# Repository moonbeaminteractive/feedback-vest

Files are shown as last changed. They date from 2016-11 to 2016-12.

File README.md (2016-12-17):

# feedback-vest
vest with haptic and visual feedback

## Circuit Diagram - main board
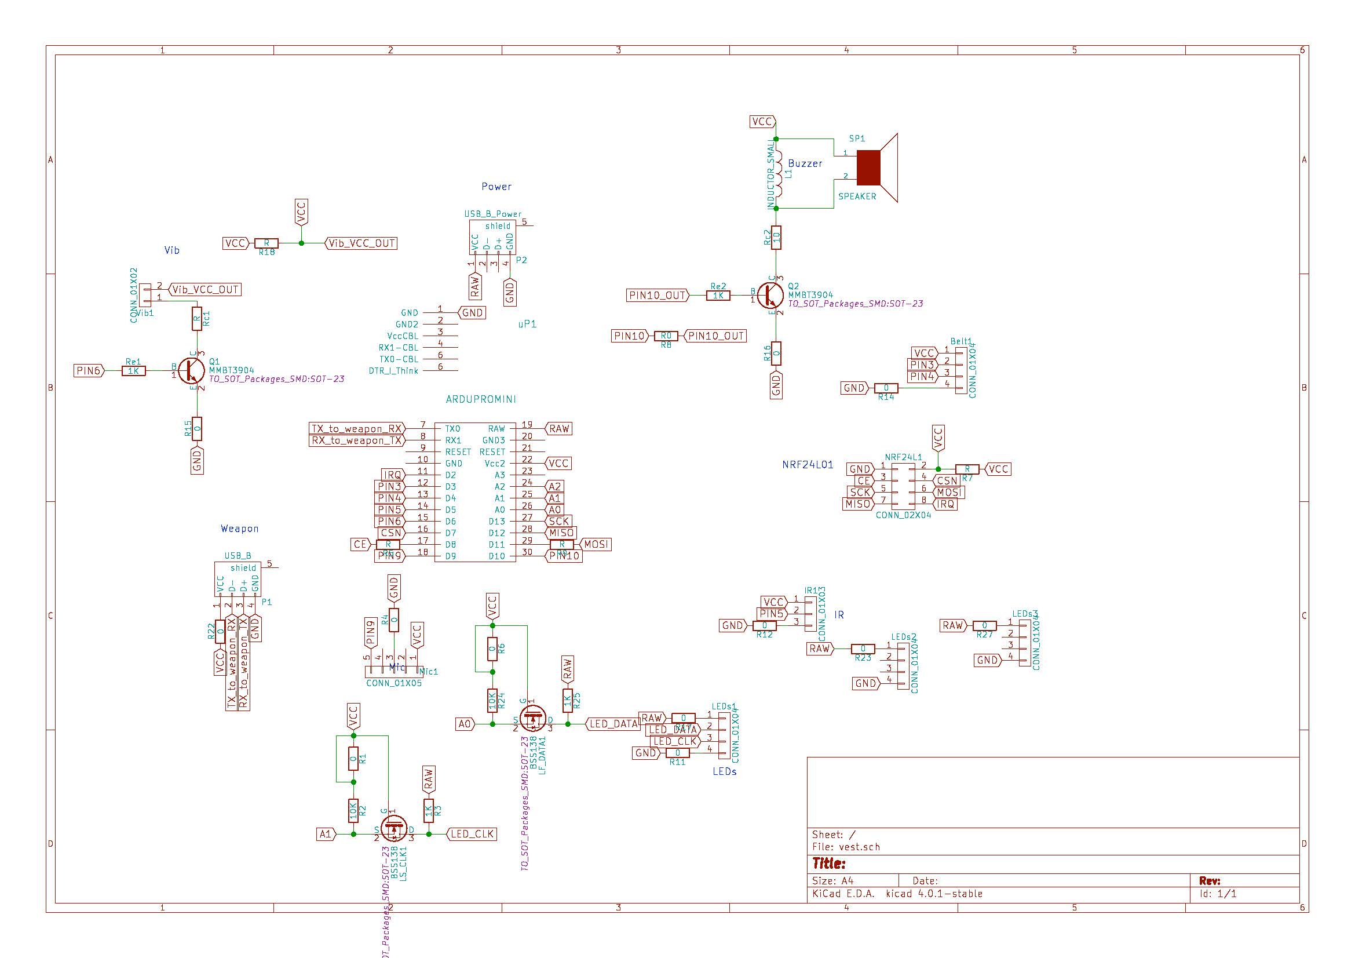
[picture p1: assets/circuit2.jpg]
alt circuit


## PCB - main board
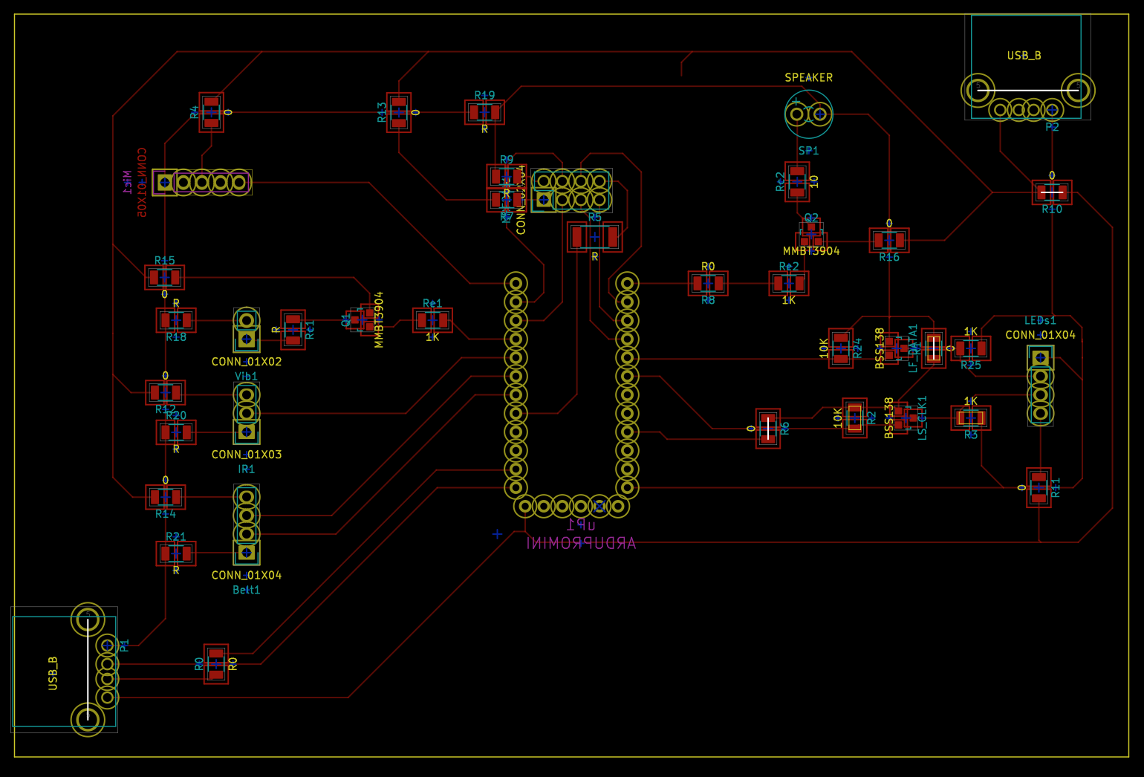
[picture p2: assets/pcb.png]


## Circuit Diagram - led Ring
alt circuit
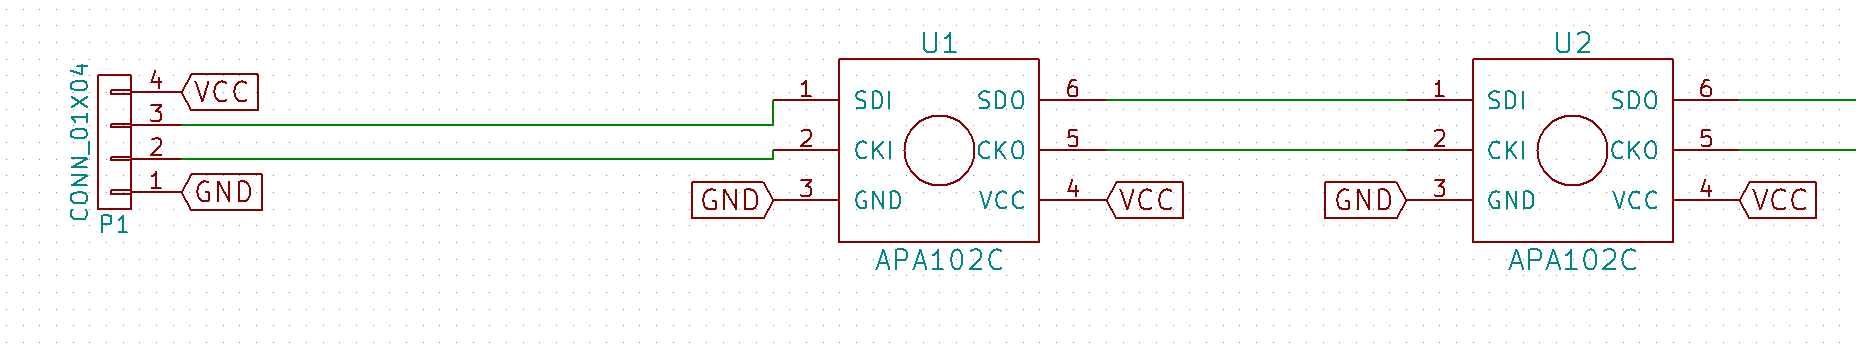
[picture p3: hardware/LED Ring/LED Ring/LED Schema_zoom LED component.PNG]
alt circuit_led component


## Circuit Diagram - led ring PCB
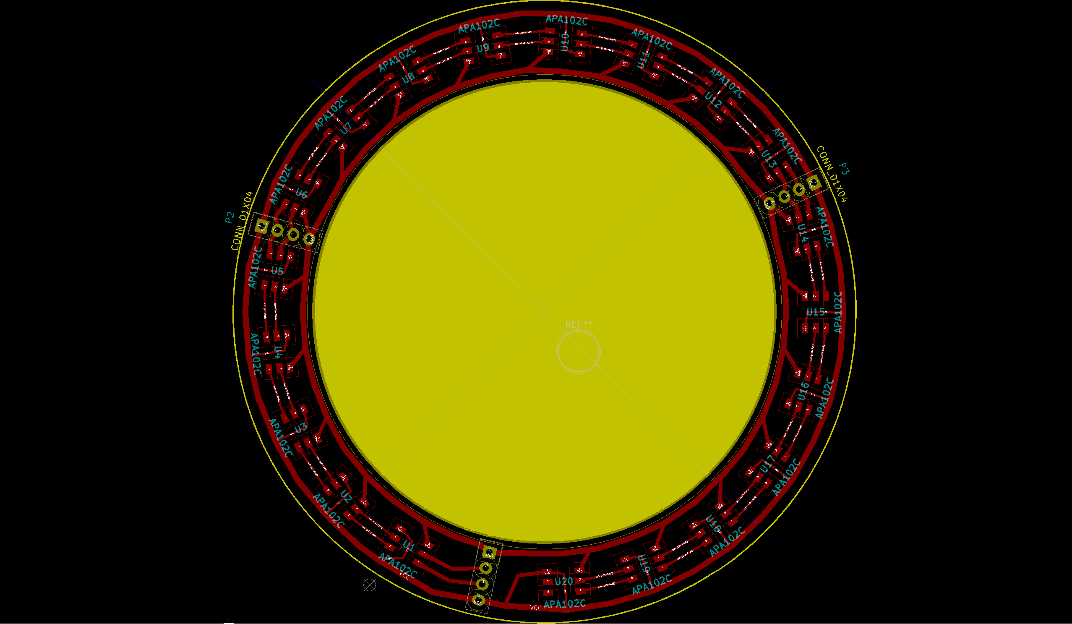
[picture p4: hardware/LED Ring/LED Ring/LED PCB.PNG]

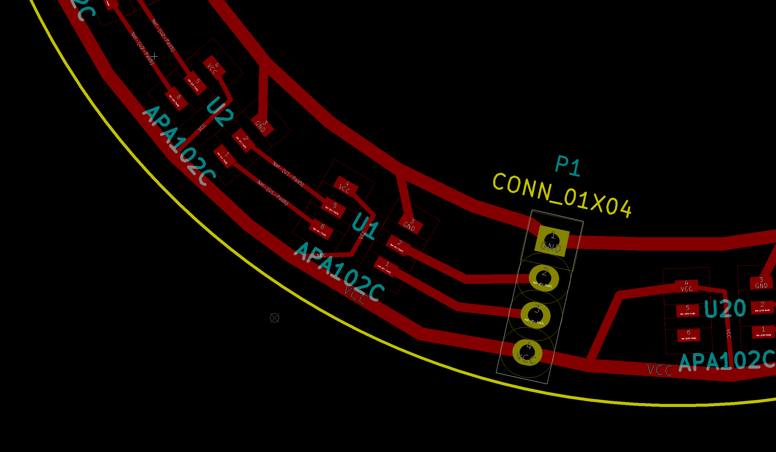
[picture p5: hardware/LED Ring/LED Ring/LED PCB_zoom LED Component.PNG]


## circuit diagram and PCB - IR sensors
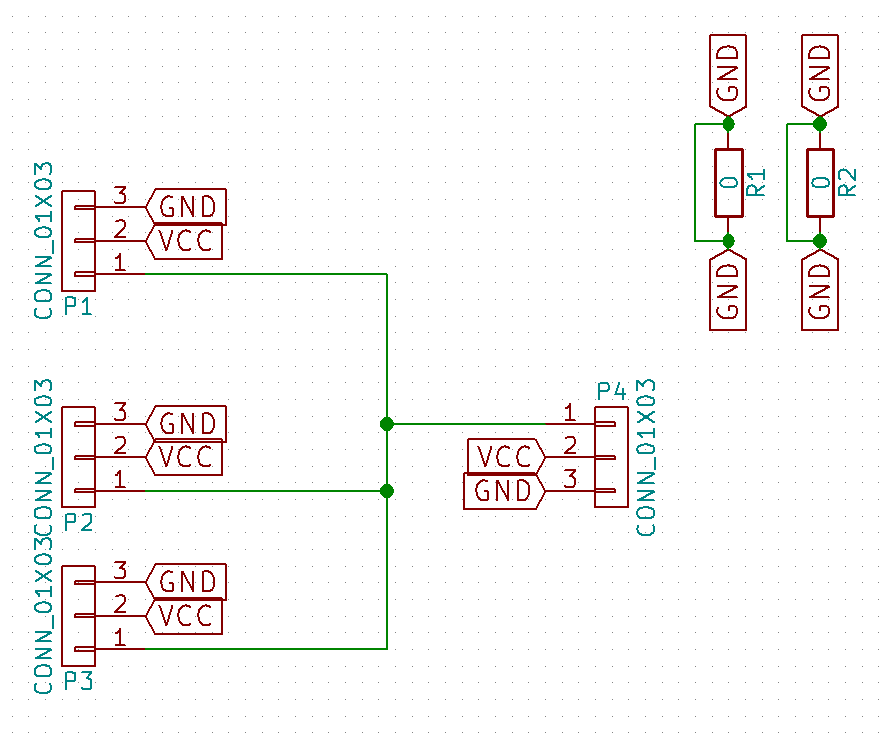
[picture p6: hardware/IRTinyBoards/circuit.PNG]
alt circuit

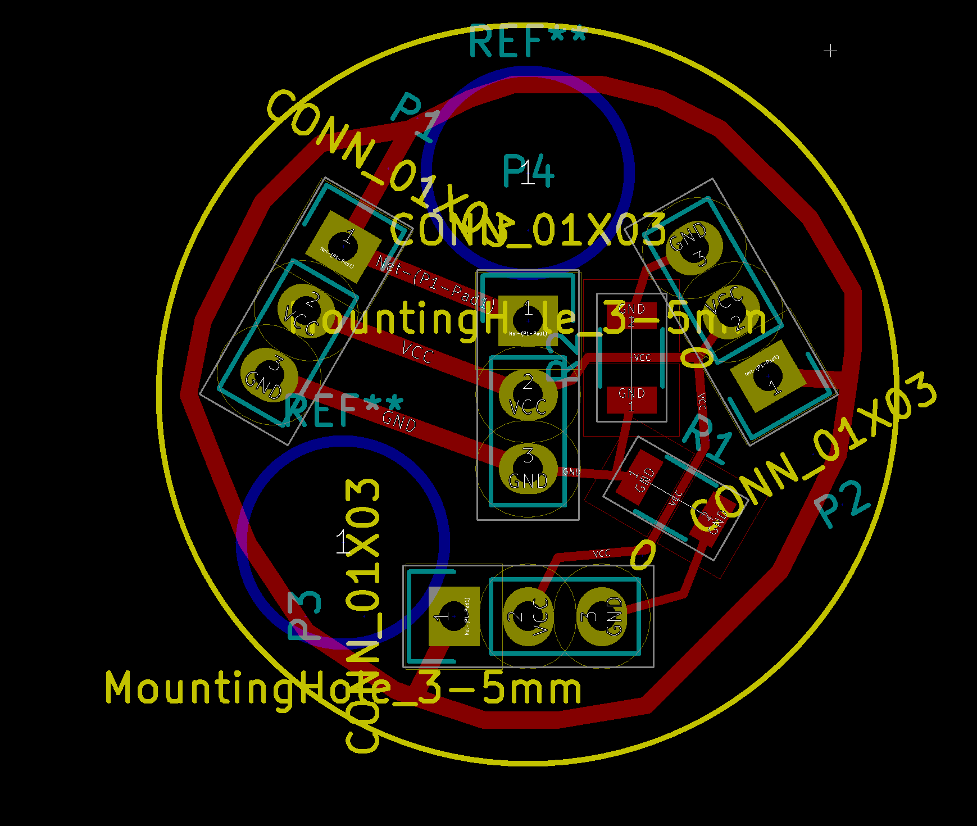
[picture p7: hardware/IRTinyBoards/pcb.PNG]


## Prototype Design
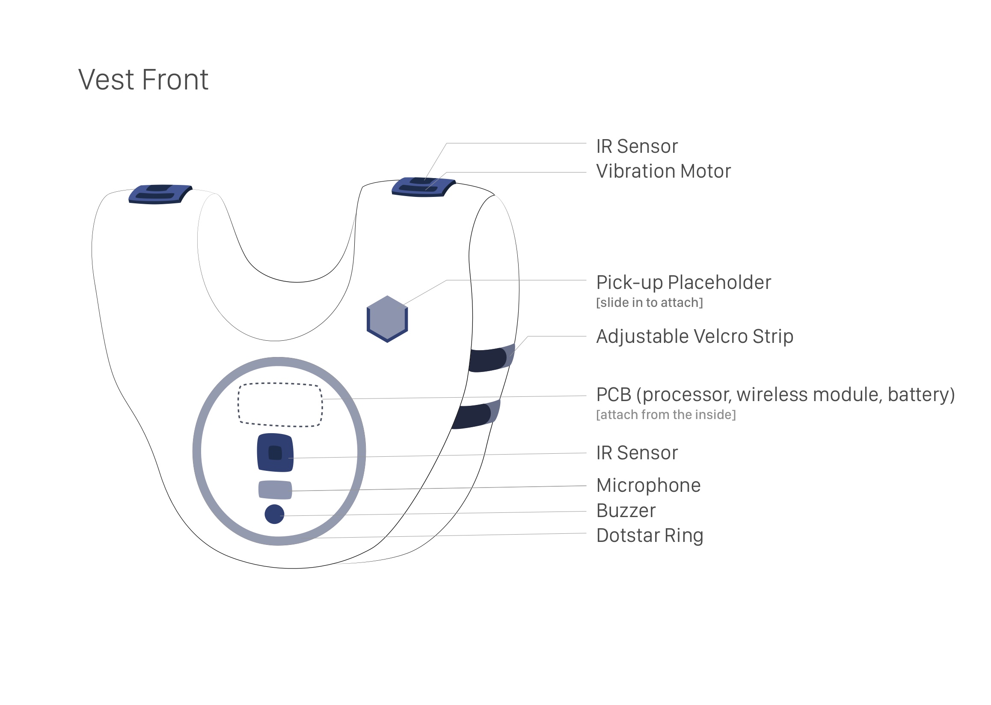
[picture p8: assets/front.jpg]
alt vest-font

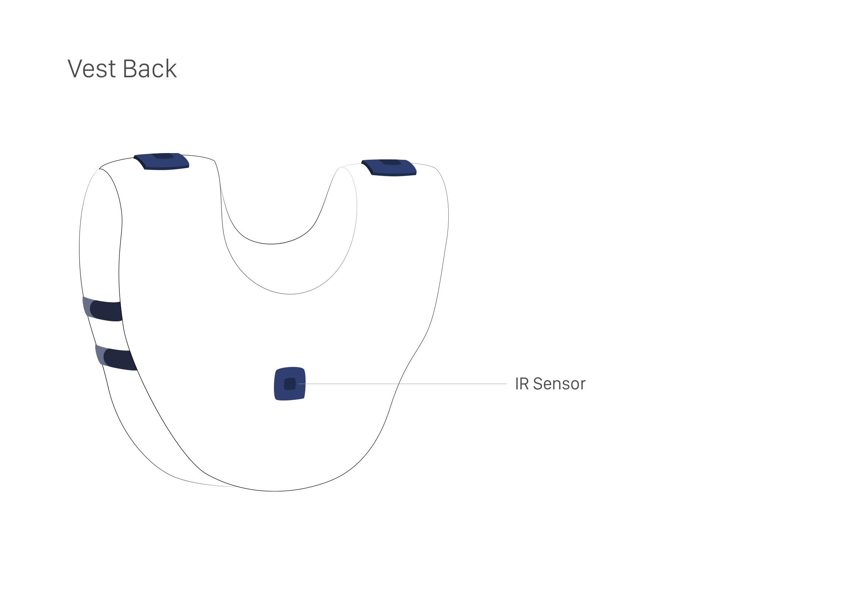
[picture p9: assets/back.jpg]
alt vest-back


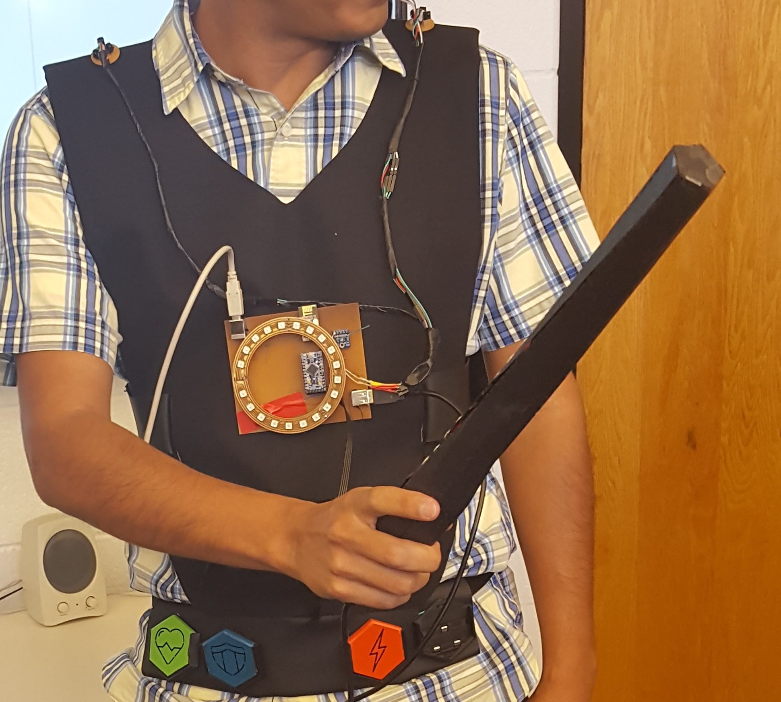
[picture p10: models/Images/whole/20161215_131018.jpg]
alt final prototype _ front


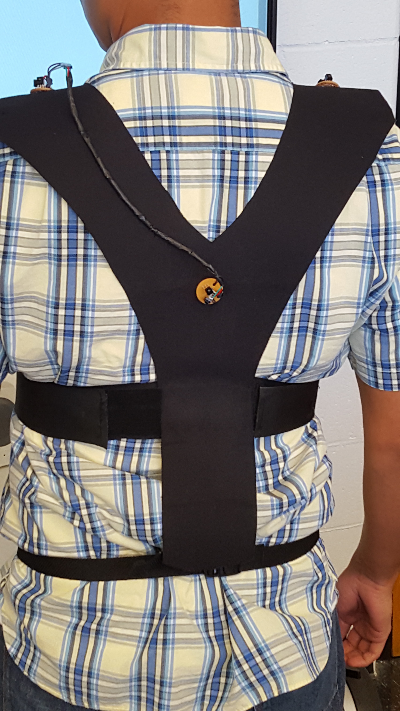
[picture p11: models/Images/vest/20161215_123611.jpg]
alt final prototype _ back


## Hardware
* nRF24L01 Wireless Transceiver
* Arduino Pro Mini
* 1838 Infrared Receiver at 38K HZ Modulation ( *4)
* Dotstar (in ring shape)
* Microphone (*1)
* Vibrator (*2)
* Speaker / buzzer
* ADC (*1)
* Battery

## Communication
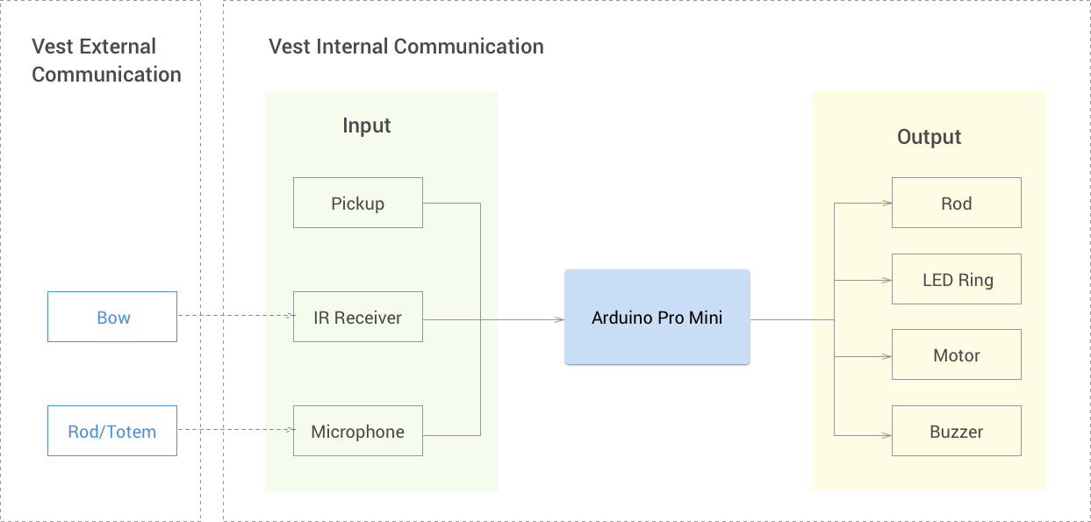
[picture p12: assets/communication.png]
alt vest-communication

https://docs.google.com/spreadsheets/d/1SZP6osHujqh5WhPNwRo56sCZVwubzTMAS0mKgGUERew/edit#gid=0

## Log
### Nov/19/2016
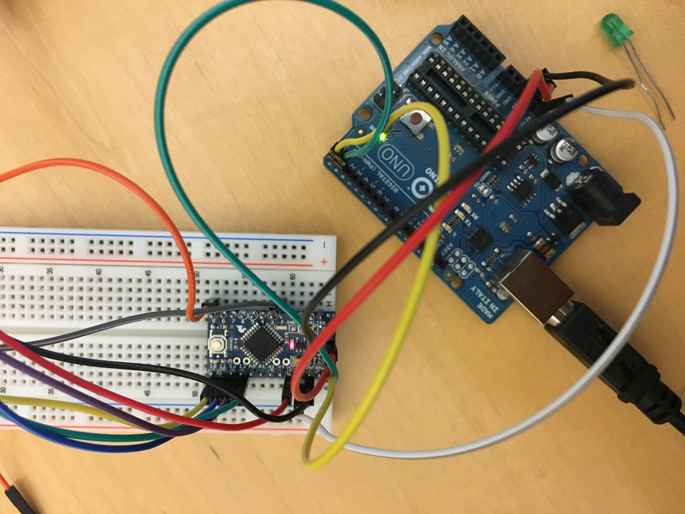
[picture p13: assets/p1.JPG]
alt testing-arduino-mini

#### Progress
* Tested Arduino Pro Mini with blink example
* Tested IR receiver with IR led, as well as TV remote controller
* Tested nRF24L01 wireless transceiver

#### Difficulties
* IR emitter is much lower than expected [suggestion from Matt: use an NPN (bjt or mosfet) transistor to supply more current]
* Order ring shape dotstar

#### Next Steps
* Test communication between multiple nRF24L01 wireless transceiver
* Check communication protocol between arm, weapon and pickup group
* Design iteration: meeting with other groups about the size of different components
* Notification system design with Buzzer/microphone and dotstar

### Nov/21/2016
#### Progress
* Tested communication between two nRF24L01 wireless transceivers, send & receive signal successfully

# Vest-to-Weapons Connection

Table of Vest-to-Weapon connections

| Pin | Signal |
| --- | --- |
| 1 | V50 |
| 2 | TX(Vest), RX(Weapon) |
| 3 | RX(Vest), TX(Weapon) |
| 4 | GND |

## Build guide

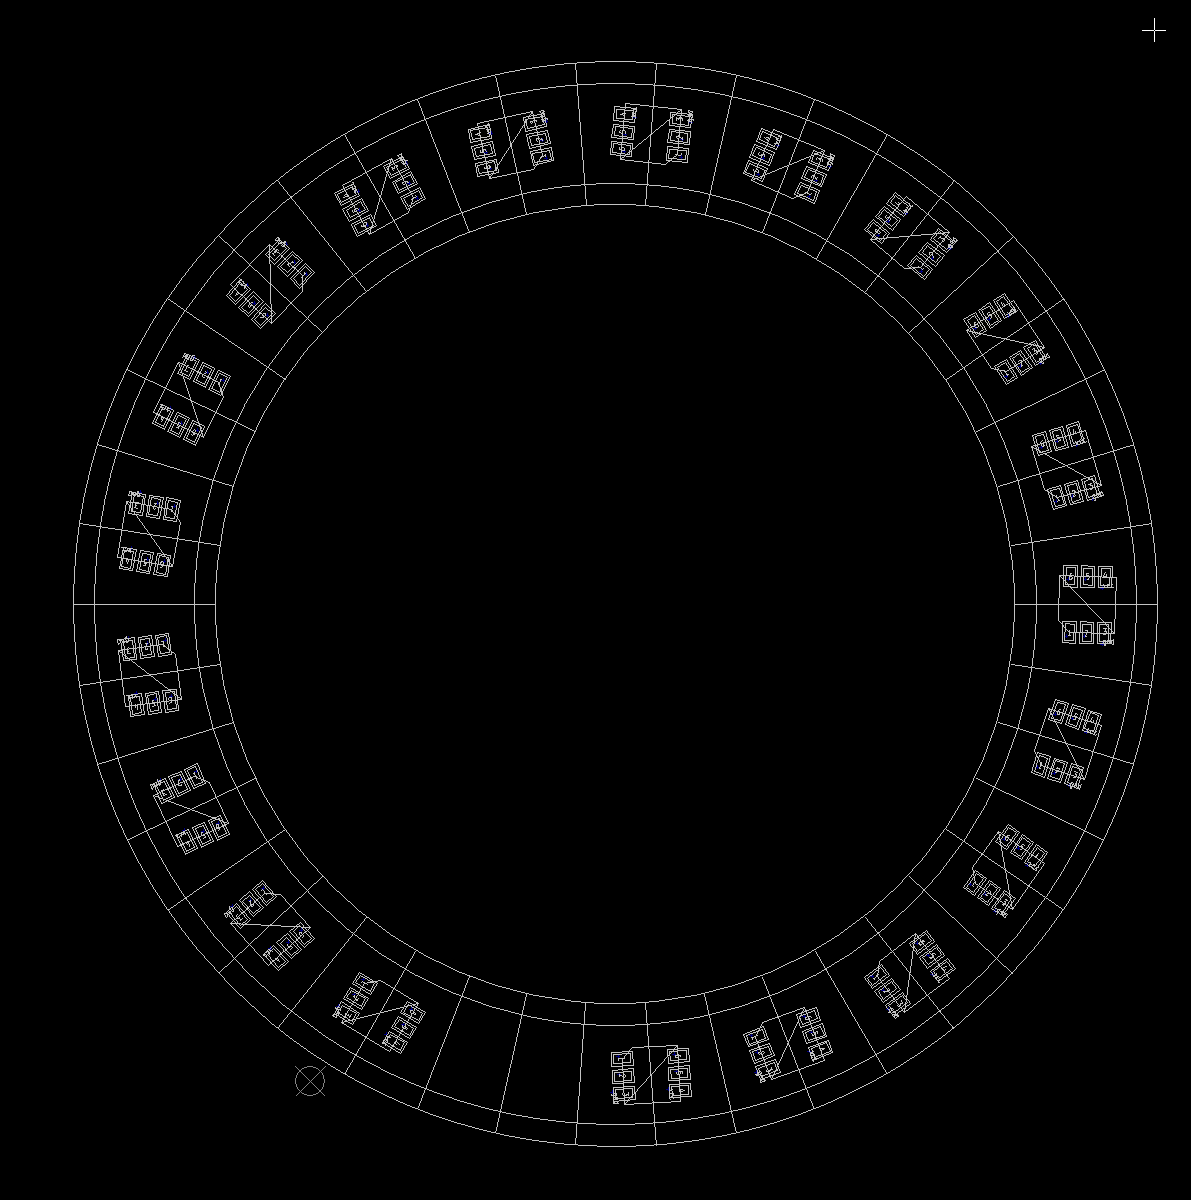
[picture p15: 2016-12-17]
hardware/LED Ring/LED Ring/imported dxf file_guideline.PNG

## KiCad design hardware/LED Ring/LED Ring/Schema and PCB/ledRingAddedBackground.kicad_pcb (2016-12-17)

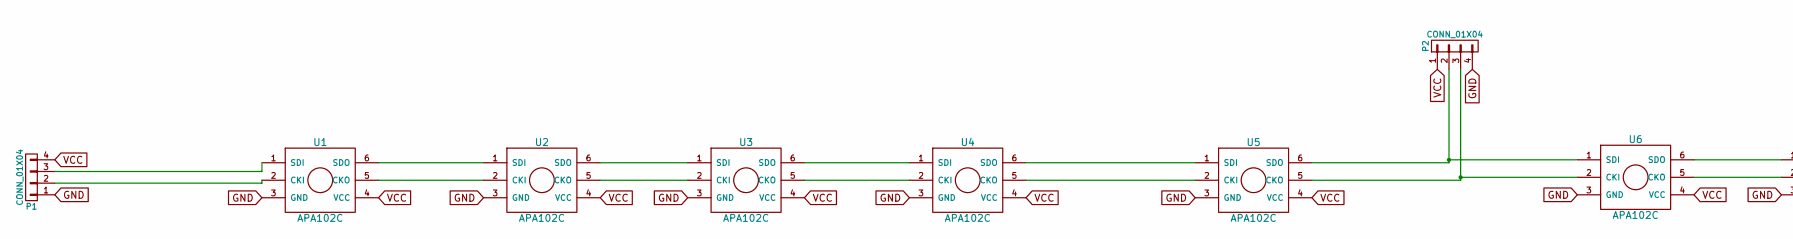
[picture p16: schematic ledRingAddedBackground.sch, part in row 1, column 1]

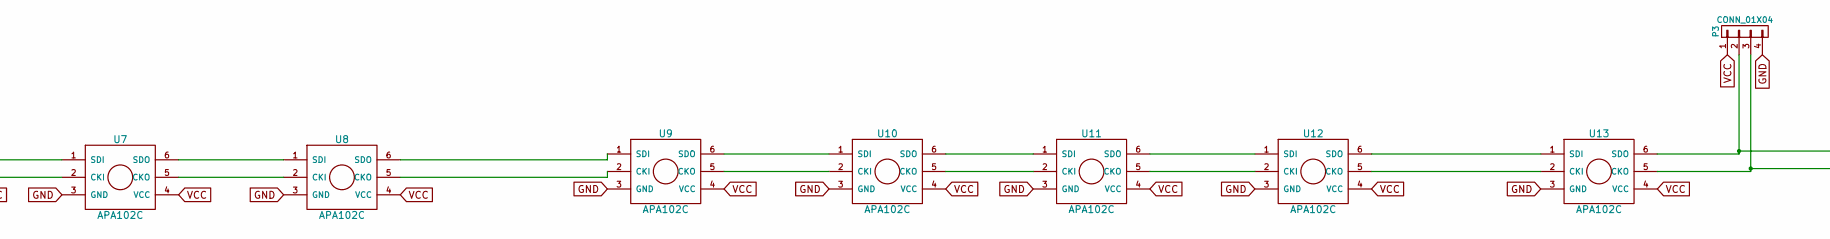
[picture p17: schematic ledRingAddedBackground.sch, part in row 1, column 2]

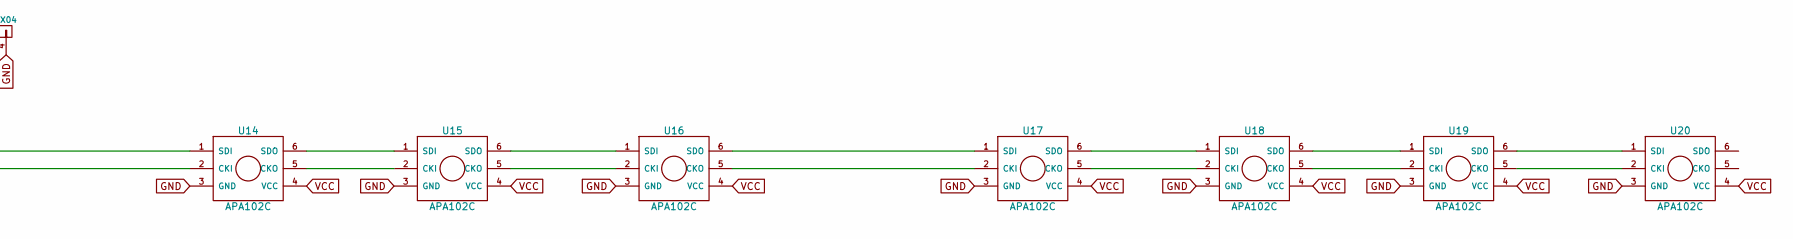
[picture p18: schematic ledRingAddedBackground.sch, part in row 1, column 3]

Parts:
P1, P2, P3: CONN_01X04; Pin_Header_Straight_1x04
U1, U2, U3, U4, U5, U6, U7, U8, U9, U10, U11, U12, U13, U14, U15, U16, U17, U18, U19, U20: APA102C; APA102C-80

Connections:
GND: P1.1, P2.4, P3.4, U1.3 (GND), U2.3 (GND), U3.3 (GND), U4.3 (GND), U5.3 (GND), U6.3 (GND), U7.3 (GND), U8.3 (GND), U9.3 (GND), U10.3 (GND), U11.3 (GND), U12.3 (GND), U13.3 (GND), U14.3 (GND), U15.3 (GND), U16.3 (GND), U17.3 (GND), U18.3 (GND), U19.3 (GND), U20.3 (GND)
unnamed: P1.2, U1.2 (CKI)
unnamed: P1.3, U1.1 (SDI)
unnamed: P2.2, U5.6 (SDO), U6.1 (SDI)
unnamed: P2.3, U5.5 (CKO), U6.2 (CKI)
unnamed: P3.2, U13.6 (SDO), U14.1 (SDI)
unnamed: P3.3, U13.5 (CKO), U14.2 (CKI)
unnamed: U1.5 (CKO), U2.2 (CKI)
unnamed: U1.6 (SDO), U2.1 (SDI)
unnamed: U2.5 (CKO), U3.2 (CKI)
unnamed: U2.6 (SDO), U3.1 (SDI)
unnamed: U3.5 (CKO), U4.2 (CKI)
unnamed: U3.6 (SDO), U4.1 (SDI)
unnamed: U4.5 (CKO), U5.2 (CKI)
unnamed: U4.6 (SDO), U5.1 (SDI)
unnamed: U6.5 (CKO), U7.2 (CKI)
unnamed: U6.6 (SDO), U7.1 (SDI)
unnamed: U7.5 (CKO), U8.2 (CKI)
unnamed: U7.6 (SDO), U8.1 (SDI)
unnamed: U8.5 (CKO), U9.2 (CKI)
unnamed: U8.6 (SDO), U9.1 (SDI)
unnamed: U9.6 (SDO), U10.1 (SDI)
unnamed: U9.5 (CKO), U10.2 (CKI)
unnamed: U10.5 (CKO), U11.2 (CKI)
unnamed: U10.6 (SDO), U11.1 (SDI)
unnamed: U11.5 (CKO), U12.2 (CKI)
unnamed: U11.6 (SDO), U12.1 (SDI)
unnamed: U12.5 (CKO), U13.2 (CKI)
unnamed: U12.6 (SDO), U13.1 (SDI)
unnamed: U14.5 (CKO), U15.2 (CKI)
unnamed: U14.6 (SDO), U15.1 (SDI)
unnamed: U15.5 (CKO), U16.2 (CKI)
unnamed: U15.6 (SDO), U16.1 (SDI)
unnamed: U16.5 (CKO), U17.2 (CKI)
unnamed: U16.6 (SDO), U17.1 (SDI)
unnamed: U17.5 (CKO), U18.2 (CKI)
unnamed: U17.6 (SDO), U18.1 (SDI)
unnamed: U18.5 (CKO), U19.2 (CKI)
unnamed: U18.6 (SDO), U19.1 (SDI)
unnamed: U19.5 (CKO), U20.2 (CKI)
unnamed: U19.6 (SDO), U20.1 (SDI)
VCC: P1.4, P2.1, P3.1, U1.4 (VCC), U2.4 (VCC), U3.4 (VCC), U4.4 (VCC), U5.4 (VCC), U6.4 (VCC), U7.4 (VCC), U8.4 (VCC), U9.4 (VCC), U10.4 (VCC), U11.4 (VCC), U12.4 (VCC), U13.4 (VCC), U14.4 (VCC), U15.4 (VCC), U16.4 (VCC), U17.4 (VCC), U18.4 (VCC), U19.4 (VCC), U20.4 (VCC)

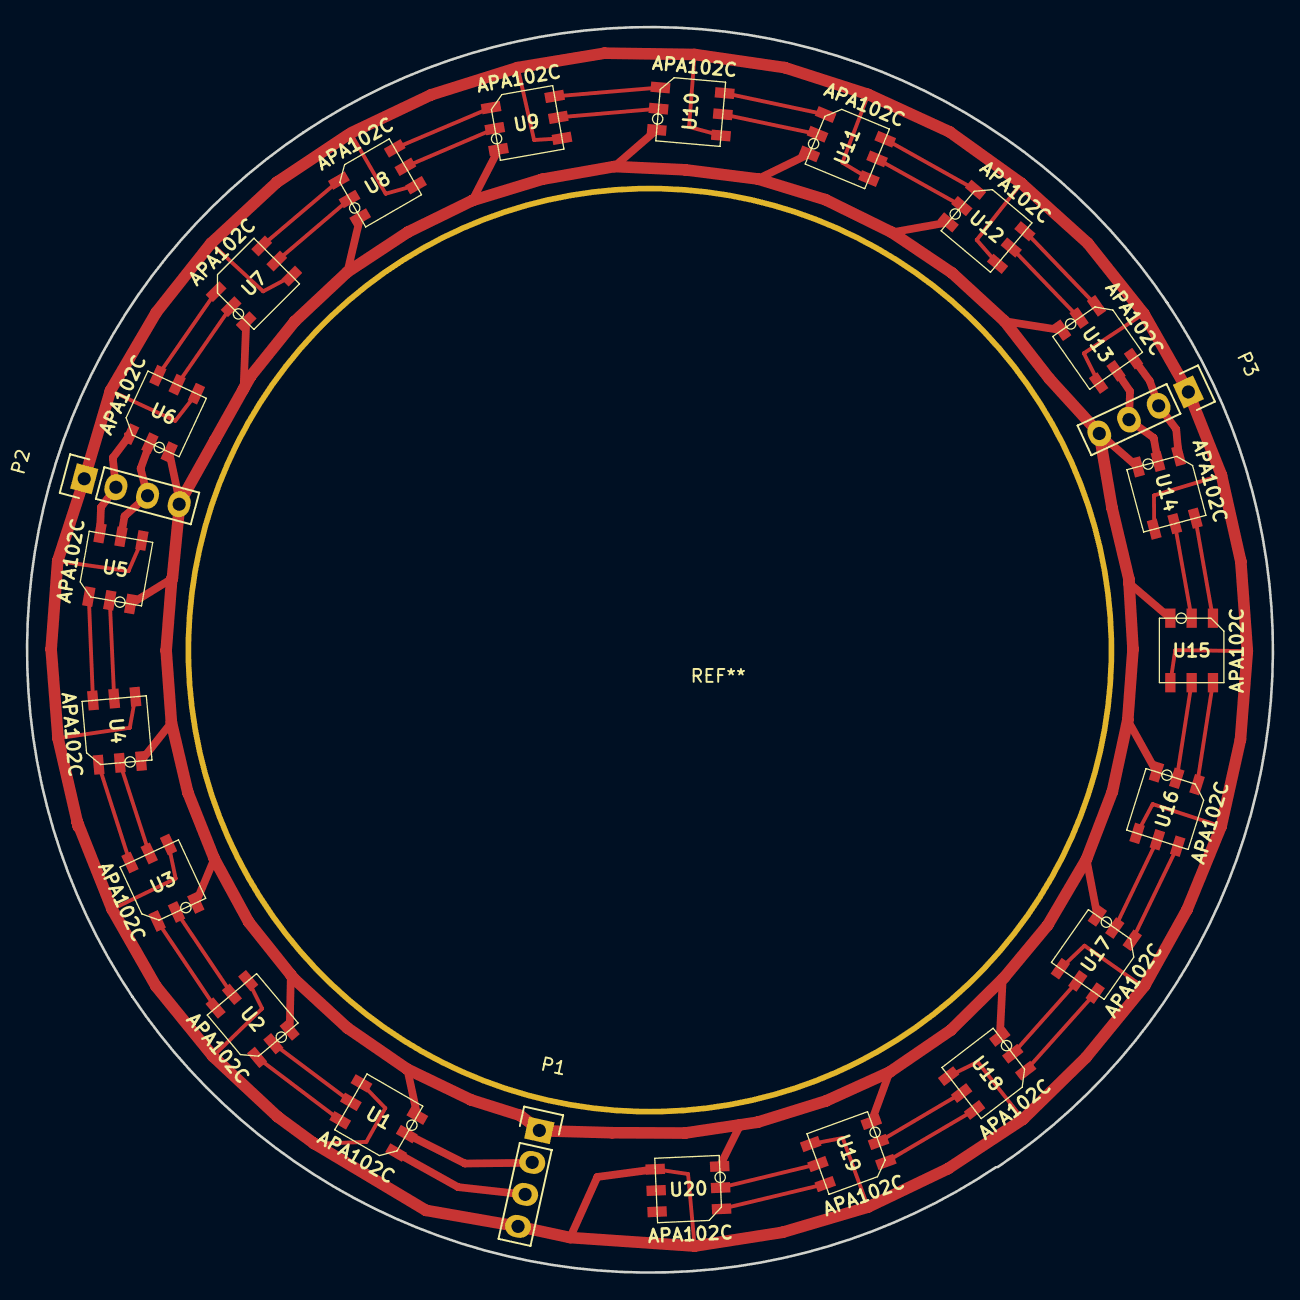
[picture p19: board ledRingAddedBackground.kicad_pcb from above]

Board: 2 copper layers, 96.6 x 96.6 mm, 23 parts (0 on the bottom side), 42 nets.

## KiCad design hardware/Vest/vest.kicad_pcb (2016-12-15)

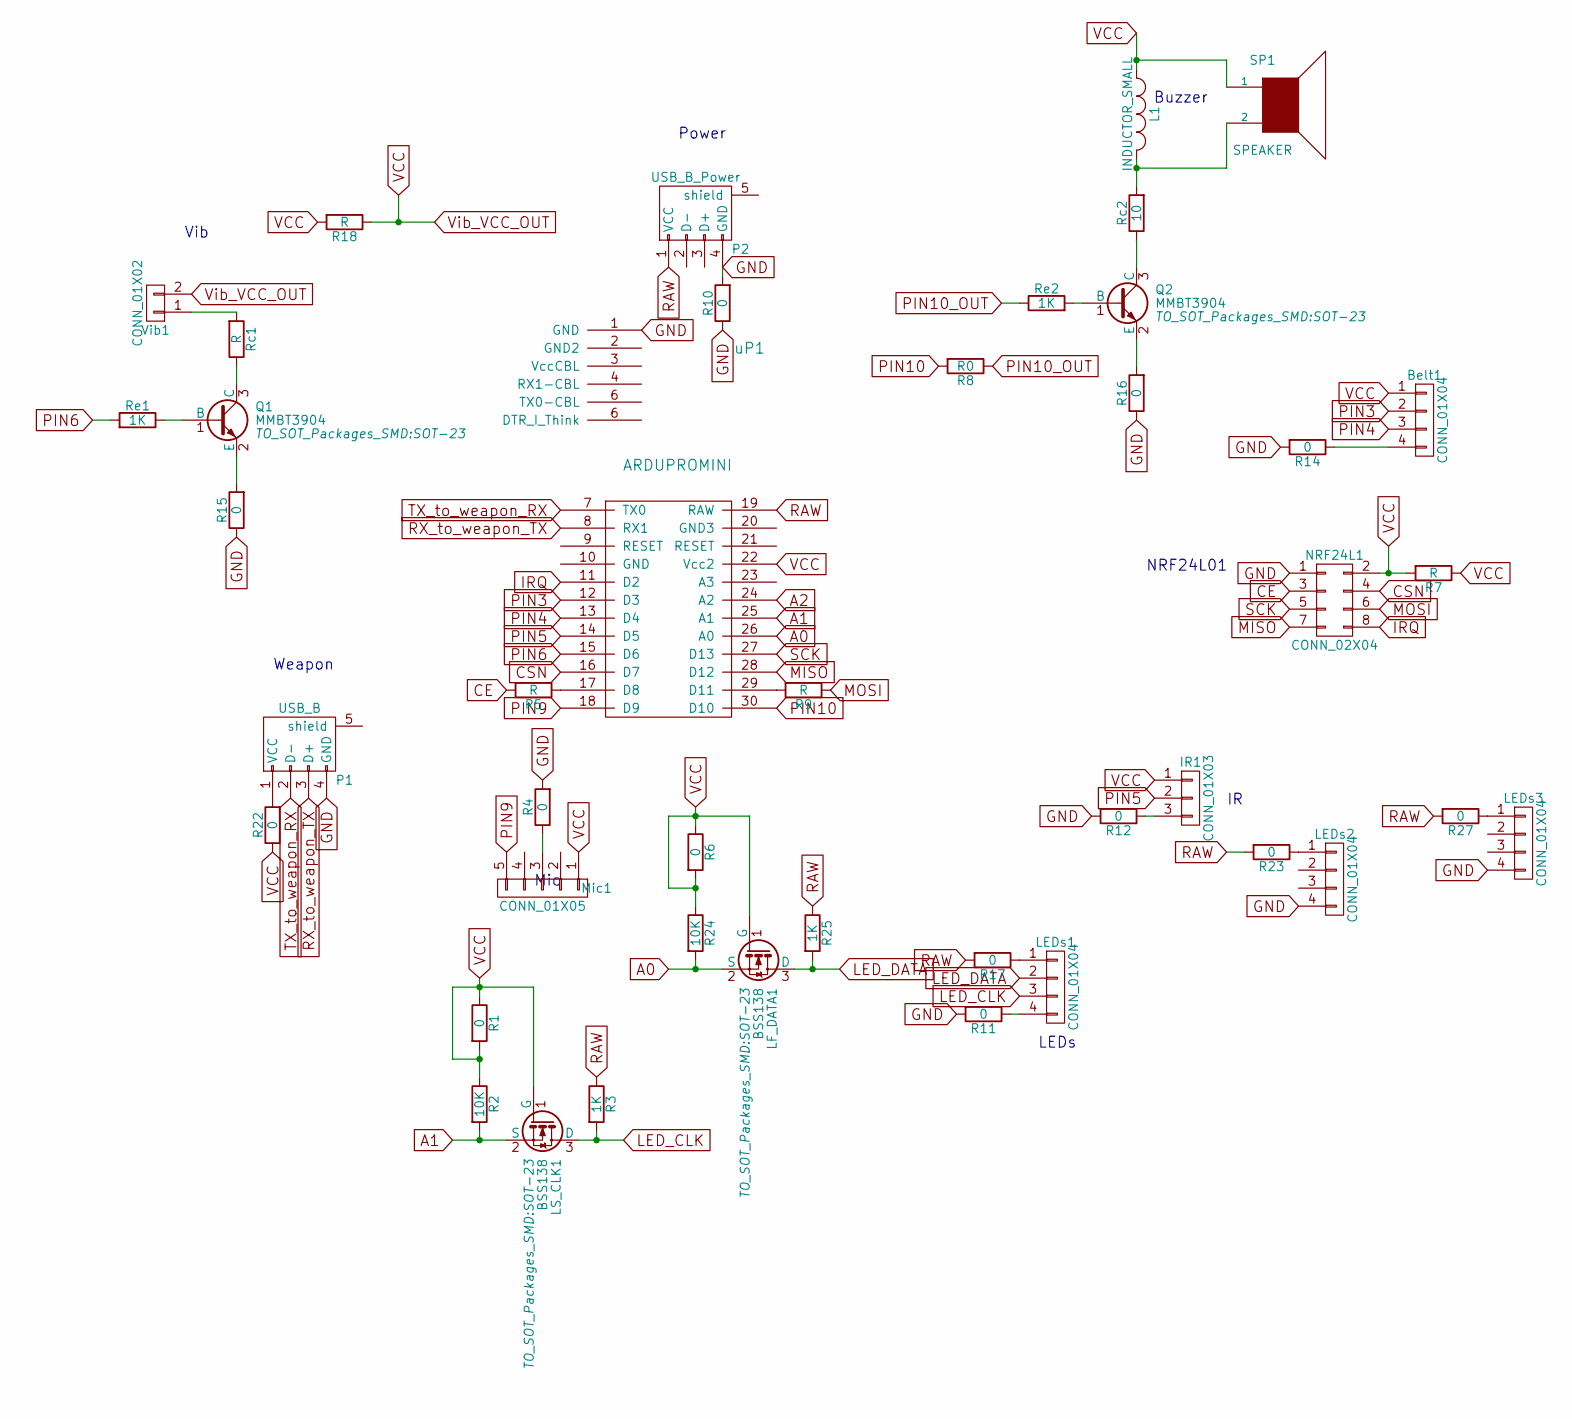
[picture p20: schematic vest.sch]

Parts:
Belt1: CONN_01X04; Pin_Header_Straight_1x04
IR1: CONN_01X03; Pin_Header_Straight_1x03
L1: INDUCTOR_SMALL
LEDs1, LEDs2, LEDs3: CONN_01X04; Pin_Header_Straight_1x04
LF_DATA1: BSS138; SOT-23
LS_CLK1: BSS138; SOT-23
Mic1: CONN_01X05; Pin_Header_Straight_1x05
NRF24L1: CONN_02X04; Pin_Header_Straight_2x04
P1: USB_B; USB_A
P2: USB_B_Power; USB_B
Q1, Q2: MMBT3904; SOT-23
R1, R4, R6, R10, R11, R12, R14, R15, R16, R17, R22, R23, R27: 0; R_1206
R2, R24: 10K; R_1206
R3, R25: 1K; R_1206
R5, R9: R; R_1206
R7, R18: R; R_2010
R8: R0; R_2512
Rc1: R; R_1206
Rc2: 10; R_1206
Re1, Re2: 1K; R_1206
SP1: SPEAKER; MagneticBuzzer_ProSignal_ABI-010-RC
Vib1: CONN_01X02; Pin_Header_Straight_1x02
uP1: ARDUPROMINI; ArduProMini

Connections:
A0: LF_DATA1.2 (S), R24.2, uP1.26 (A0)
A1: LS_CLK1.2 (S), R2.2, uP1.25 (A1)
A2: uP1.24 (A2)
CE: NRF24L1.3, R5.2
CSN: NRF24L1.4, uP1.16 (D7)
GND: LEDs2.4, LEDs3.4, NRF24L1.1, P1.4 (GND), P2.4 (GND), R4.2, R10.1, R10.2, R11.2, R12.2, R14.2, R15.1, R16.1, uP1.1 (GND)
IRQ: NRF24L1.8, uP1.11 (D2)
LED_CLK: LEDs1.3, LS_CLK1.3 (D), R3.2
LED_DATA: LEDs1.2, LF_DATA1.3 (D), R25.2
MISO: NRF24L1.7, uP1.28 (D12)
MOSI: NRF24L1.6, R9.1
unnamed: Belt1.4, R14.1
unnamed: IR1.3, R12.1
unnamed: L1.2, Rc2.2, SP1.2
unnamed: LEDs1.1, R17.1
unnamed: LEDs1.4, R11.1
unnamed: LEDs2.1, R23.1
unnamed: LEDs3.1, R27.1
unnamed: Mic1.3, R4.1
unnamed: P1.1 (VCC), R22.2
unnamed: Q1.1 (B), Re1.1
unnamed: Q1.2 (E), R15.2
unnamed: Q1.3 (C), Rc1.1
unnamed: Q2.1 (B), Re2.2
unnamed: Q2.2 (E), R16.2
unnamed: Q2.3 (C), Rc2.1
unnamed: R5.1, uP1.17 (D8)
unnamed: R9.2, uP1.29 (D11)
unnamed: Rc1.2, Vib1.1
PIN3: Belt1.2, uP1.12 (D3)
PIN4: Belt1.3, uP1.13 (D4)
PIN5: IR1.2, uP1.14 (D5)
PIN6: Re1.2, uP1.15 (D6)
PIN9: Mic1.5, uP1.18 (D9)
PIN10: R8.2, uP1.30 (D10)
PIN10_OUT: R8.1, Re2.1
RAW: P2.1 (VCC), R3.1, R17.2, R23.2, R25.1, R27.2, uP1.19 (RAW)
RX_to_weapon_TX: P1.3 (D+), uP1.8 (RX1)
SCK: NRF24L1.5, uP1.27 (D13)
TX_to_weapon_RX: P1.2 (D-), uP1.7 (TX0)
VCC: Belt1.1, IR1.1, L1.1, LF_DATA1.1 (G), LS_CLK1.1 (G), Mic1.1, NRF24L1.2, R1.1, R1.2, R2.1, R6.1, R6.2, R7.1, R7.2, R18.1, R18.2, R22.1, R24.1, SP1.1, Vib1.2, uP1.22 (Vcc2)

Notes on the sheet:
Buzzer
Vib
Mic
LEDs
NRF24L01
Power
Weapon

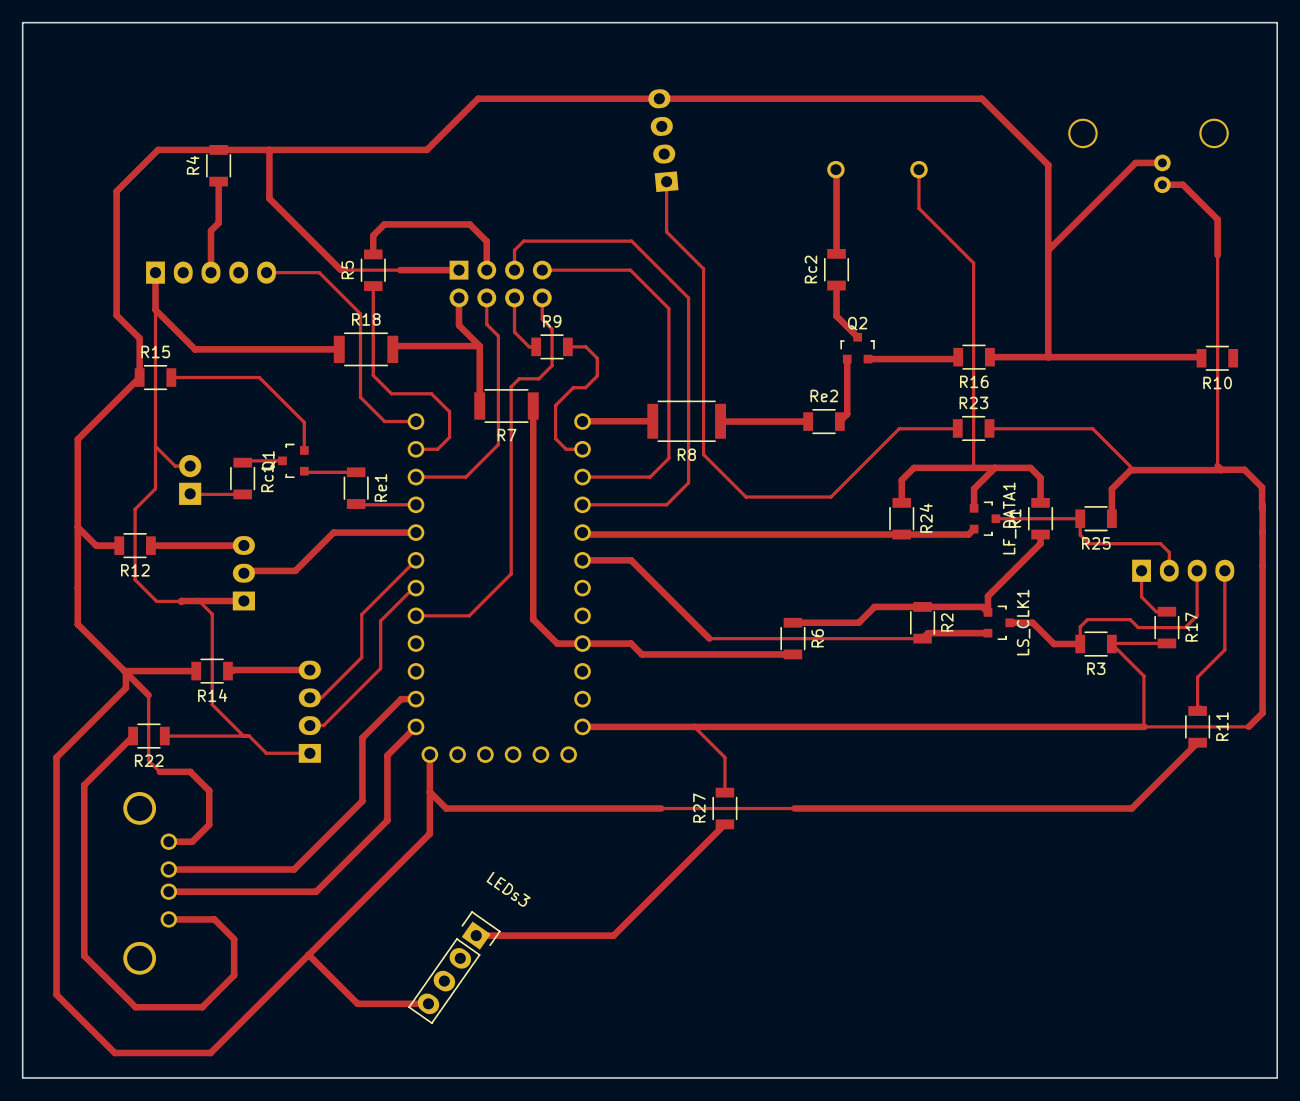
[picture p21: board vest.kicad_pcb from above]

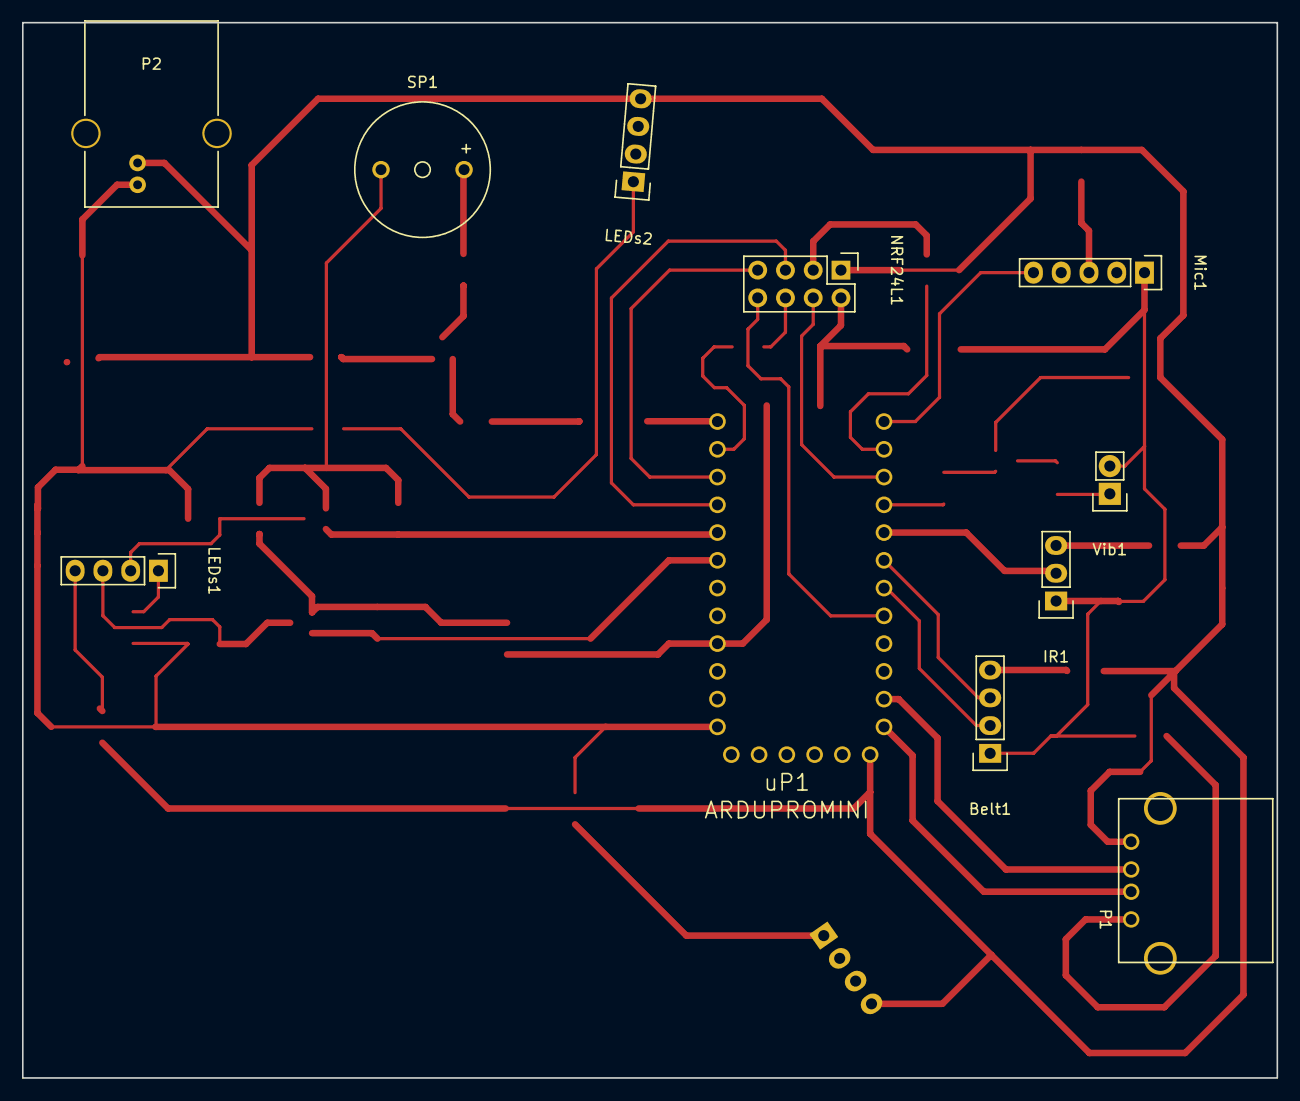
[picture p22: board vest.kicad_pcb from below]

Board: 2 copper layers, 114.8 x 96.6 mm, 42 parts (11 on the bottom side), 40 nets.

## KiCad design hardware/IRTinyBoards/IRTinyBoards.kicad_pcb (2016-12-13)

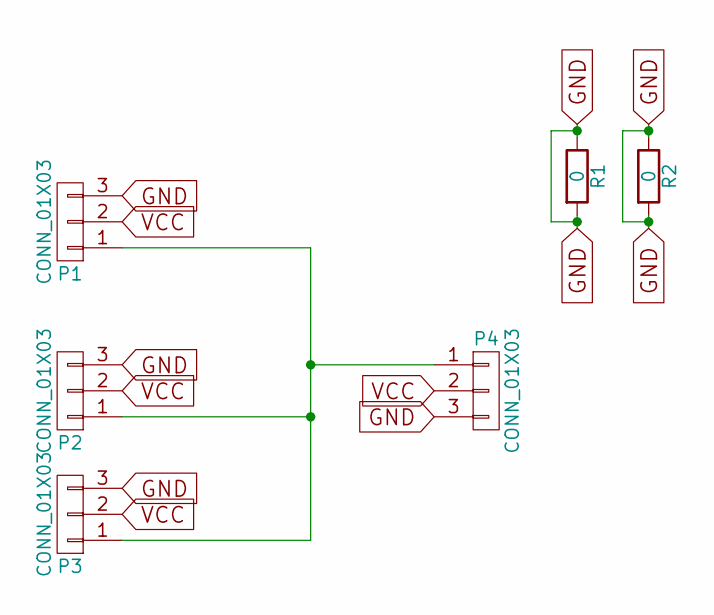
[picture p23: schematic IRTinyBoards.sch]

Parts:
P1, P2, P3, P4: CONN_01X03; Pin_Header_Straight_1x03
R1, R2: 0; R_1206

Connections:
GND: P1.3, P2.3, P3.3, P4.3, R1.1, R1.2, R2.1, R2.2
unnamed: P1.1, P2.1, P3.1, P4.1
VCC: P1.2, P2.2, P3.2, P4.2

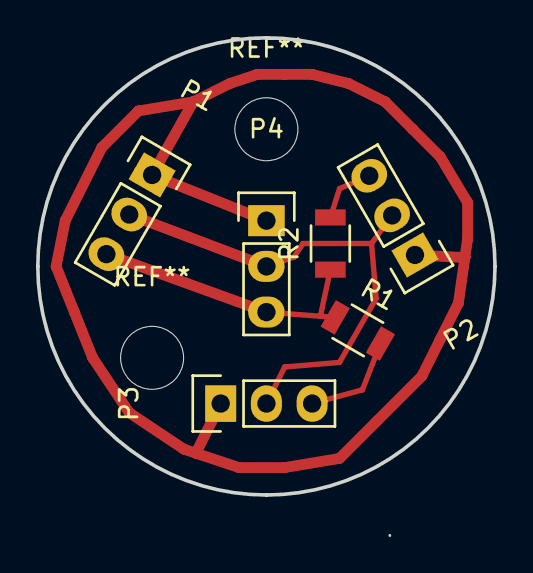
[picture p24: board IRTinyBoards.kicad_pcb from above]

Board: 2 copper layers, 25.4 x 27.7 mm, 6 parts (0 on the bottom side), 3 nets.

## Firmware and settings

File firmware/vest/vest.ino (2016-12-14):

#include <SoftwareSerial.h>
#include <avr/pgmspace.h>
#include <MorseEnDecoder.h>
#include "pitches.h"


// Pin Mapping
#define TXPIN 0
#define RXPIN 1
#define PICKUPPIN1 3
#define PICKUPPIN2 4
#define IR_RECEIVER 5
#define VIBPIN 6
#define MICROPHONEPIN 9
#define BUZZERPIN 10


/***********************************************************/
/**************   Microphone communication   ***************/
/***********************************************************/

// Instantiate Morse objects
morseDecoder morseInput(MICROPHONEPIN, MORSE_AUDIO, MORSE_ACTIVE_LOW);

// Variables dealing with formatting the output somewhat
// by inserting CR's (carriage returns)
long lastTransmissionTime;
long currentTime;
boolean transmissionEnded = true; // Flag to mark old transmission is finished

// Minimum transmission pause time to insert carriage returns (CR)
// Adjust depending on Morse speed. IE 13 wpm = 646 ms between words (no CR).
const long transmissionPaused   = 1000;


/***********************************************************/
/**************   Weapon Serial connection     *************/
/***********************************************************/
SoftwareSerial weaponSerial(RXPIN, TXPIN); // RX, TX

void setup() {
  // put your setup code here, to run once:
    Serial.begin(9600);
    Serial.println("Morse EnDecoder demo");

    /*
    ** Microphone
    */
    // Setting morse speed in wpm (word per minute, 13 is default)
    morseInput.setspeed(13);
    lastTransmissionTime = (long)millis();

    /*
    ** Weapon serial
    */
    while(!Serial)
    {
        // wait for serial port to connect.
    }




}



void loop()
{
    /*
    ** Microphone
    */
    currentTime = (long)millis();
  
    // Needs to call these once per loop
    morseInput.decode();
    // RECEIVE MORSE (INPUT)
    // If a character is decoded from the input, write it to serial port
    if (morseInput.available())
    {
        Serial.println("**");
        // Get decoded Morse code character and write it to serial port/monitor
        char receivedMorse = morseInput.read();
        Serial.println(receivedMorse);
        Serial.println("--");
        
        // A little error checking    
        if (receivedMorse == '#') Serial.println("< ERROR:too many morse signals! >");
    } 

    // Check if ongoing transmission (not yet transmission pause)
    if (morseInput.morseSignalState == true)
    {
        // reset last transmission timer and flag
        lastTransmissionTime = currentTime;
        transmissionEnded = false;
    }

    // Format output with carriage returns after a transmission pause
    if ((currentTime - lastTransmissionTime) > transmissionPaused)
    {
        if (transmissionEnded == false)
        {
            // Separate the transmissions somewhat in the serial monitor with CR's
            for (int cr=0; cr<2; cr++) Serial.println("");  // some carriage returns..
          
            // Finally set the flag to prevent continous carriage returns
            transmissionEnded = true;
        }
    }

    /*
    ** Weapon serial testing
    */

    // if(weaponSerial.available()){
    //     Serial.write(weaponSerial.read());
    // }
    // if(Serial.available()){
    //     weaponSerial.write(Serial.read());
    // }

}

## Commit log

2016-11-19 Added a picture of testing the IR sensor
2016-12-12 Added pcb design
    [_saved_vest.sch, vest.kicad_pcb, vest.sch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]
2016-12-12 Added pcb and circuit diagram
2016-12-13 Updated pcb
    [vest.kicad_pcb, vest.sch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]
2016-12-13 changed transistor from 2222 to MMBT3904
    [vest-Edge.Cuts.gbr, vest-F.Cu.gbr, vest.drl]
2016-12-13 updated pcb: change track passing through 1206 from 0.6 to 0.3
    [vest.kicad_pcb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]
2016-12-13 Added 2 more connectors
    [vest.kicad_pcb, vest.sch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]
2016-12-13 modified irtinyboards to be at 120 degrees on a circular board
    [IRTinyBoards.kicad_pcb, IRTinyBoards.sch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]
2016-12-14 minor changes to the vest schematic
    [_saved_vest.sch, vest.sch]
2016-12-17 Create led ring
2016-12-17 Add files via upload
    LED Ring - Schema and PCB files
    [ledRingAddedBackground.kicad_pcb, ledRingAddedBackground.sch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]
2016-12-17 led Ring circuit diagram and pcb Updated
2016-12-17 led ring circuit diagram and pcb
2016-12-17 IR sensors circuit diagram and pcb updated
2016-12-17 physical prototype updated
